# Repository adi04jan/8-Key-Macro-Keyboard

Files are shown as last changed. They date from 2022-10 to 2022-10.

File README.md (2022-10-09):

# Macro Keyboard

This project was build to provide a convinent way to control some basic task while working. Also this was a way for me to explore CH551G a wonderfull IC with so much potential.
Although the code is still a bit messy but it does what it is supposed to do.

The project was build around in a weekend so maybe some parts are not polished and may have a lot of bugs but what can we get in a weekend right !

I had a CNC milling machine lying around so I made a simple PCB with lowest possible jumpers and lowest necessary components to make the PCB in single side and with minimum assembley.

PCB Files are located inside `Macro Mini Keypad PCB Files`
and Source code is in `8xMacro_Keypad_main/8xMain_key`

## Code

Before programming the CH551G please follow [this guide](https://github.com/DeqingSun/ch55xduino "this guide") .

Once the Arduino is configured to compile code for ch551G go to `tools > User setting > 148B USB RAM` and slect this setting.

Now you can compile and upload the code in the Board via USB just remember to keep pressed the mini button behind the USB connetor while connecting the USB cable.

### Touch Switch config

There are 2 touch switch that need to be wired externally which can change the keyboard modes. 
For initial code it only change the copy paste command as in Linux terminal normal `ctrl + c `doesnt work but `ctrl + shift + c ` work.

in the 3D file behind the arrows a simple copper tap can be stuck and using wire can be connected to the pin 2 and 3 of the CH551G to change mode UP and Down.

### Changing the Keypress

Keypress can be changed in the attached Key_config.h file .
just replace the segment inside the function `Keyboard_press(   );` with what ever keypress you want to perform.
all the key press command are listed below

```

#define KEY_LEFT_CTRL   0x80
#define KEY_LEFT_SHIFT    0x81
#define KEY_LEFT_ALT    0x82
#define KEY_LEFT_GUI    0x83
#define KEY_RIGHT_CTRL    0x84
#define KEY_RIGHT_SHIFT   0x85
#define KEY_RIGHT_ALT   0x86
#define KEY_RIGHT_GUI   0x87

#define KEY_UP_ARROW    0xDA
#define KEY_DOWN_ARROW    0xD9
#define KEY_LEFT_ARROW    0xD8
#define KEY_RIGHT_ARROW   0xD7
#define KEY_BACKSPACE   0xB2
#define KEY_TAB       0xB3
#define KEY_RETURN      0xB0
#define KEY_ESC       0xB1
#define KEY_INSERT      0xD1
#define KEY_DELETE      0xD4
#define KEY_PAGE_UP     0xD3
#define KEY_PAGE_DOWN   0xD6
#define KEY_HOME      0xD2
#define KEY_END       0xD5
#define KEY_CAPS_LOCK   0xC1
#define KEY_F1        0xC2
#define KEY_F2        0xC3
#define KEY_F3        0xC4
#define KEY_F4        0xC5
#define KEY_F5        0xC6
#define KEY_F6        0xC7
#define KEY_F7        0xC8
#define KEY_F8        0xC9
#define KEY_F9        0xCA
#define KEY_F10       0xCB
#define KEY_F11       0xCC
#define KEY_F12       0xCD
#define KEY_F13       0xF0
#define KEY_F14       0xF1
#define KEY_F15       0xF2
#define KEY_F16       0xF3
#define KEY_F17       0xF4
#define KEY_F18       0xF5
#define KEY_F19       0xF6
#define KEY_F20       0xF7
#define KEY_F21       0xF8
#define KEY_F22       0xF9
#define KEY_F23       0xFA
#define KEY_F24       0xFB

 CONSUMER_POWER    = 0x30,
    CONSUMER_SLEEP = 0x32,
    
    MEDIA_RECORD = 0xB2,
    MEDIA_FAST_FORWARD    = 0xB3,
    MEDIA_REWIND    = 0xB4,
    MEDIA_NEXT    = 0xB5,
    MEDIA_PREVIOUS    = 0xB6,
    MEDIA_PREV    = 0xB6, // Alias
    MEDIA_STOP    = 0xB7,
    MEDIA_PLAY_PAUSE    = 0xCD,
    MEDIA_PAUSE    = 0xB0,
    
    MEDIA_VOLUME_MUTE    = 0xE2,
    MEDIA_VOL_MUTE = 0xE2, // Alias
    MEDIA_VOLUME_UP    = 0xE9,
    MEDIA_VOL_UP    = 0xE9, // Alias
    MEDIA_VOLUME_DOWN    = 0xEA,
    MEDIA_VOL_DOWN    = 0xEA, // Alias
    
    CONSUMER_BRIGHTNESS_UP = 0x006F,
    CONSUMER_BRIGHTNESS_DOWN = 0x0070,
    
    CONSUMER_SCREENSAVER = 0x19e,
    
    CONSUMER_PROGRAMMABLE_BUTTON_CONFIGURATION = 0x182,
    CONSUMER_CONTROL_CONFIGURATION = 0x183,
    CONSUMER_EMAIL_READER    = 0x18A,
    CONSUMER_CALCULATOR    = 0x192,
    CONSUMER_EXPLORER    = 0x194,
    
    CONSUMER_BROWSER_HOME    = 0x223,
    CONSUMER_BROWSER_BACK    = 0x224,
    CONSUMER_BROWSER_FORWARD    = 0x225,
    CONSUMER_BROWSER_REFRESH    = 0x227,
    CONSUMER_BROWSER_BOOKMARKS    = 0x22A,

    // Consumer_Page_(0x0C)    0x15
    HID_CONSUMER_UNASSIGNED        = 0x00,
    HID_CONSUMER_NUMERIC_KEY_PAD    = 0x02,    // HID type NARY
    HID_CONSUMER_PROGRAMMABLE_BUTTONS    = 0x03,    // HID type NARY
    HID_CONSUMER_MICROPHONE_CA    = 0x04,
    HID_CONSUMER_HEADPHONE_CA    = 0x05,
    HID_CONSUMER_GRAPHIC_EQUALIZER_CA    = 0x06,
    // Reserved    = 0x07-1F
    HID_CONSUMER_PLUS_10    = 0x20,    // HID type OSC
    HID_CONSUMER_PLUS_100    = 0x21,    // HID type OSC
    HID_CONSUMER_AM_SLASH_PM    = 0x22,    // HID type OSC
    // Reserved    = 0x23-3F
    HID_CONSUMER_POWER    = 0x30,    // HID type OOC
    HID_CONSUMER_RESET    = 0x31,    // HID type OSC
    HID_CONSUMER_SLEEP    = 0x32,    // HID type OSC
    HID_CONSUMER_SLEEP_AFTER    = 0x33,    // HID type OSC
    HID_CONSUMER_SLEEP_MODE    = 0x34,    // HID type RTC
    HID_CONSUMER_ILLUMINATION    = 0x35,    // HID type OOC
    HID_CONSUMER_FUNCTION_BUTTONS    = 0x36,    // HID type NARY
    // Reserved    = 0x37-3F
    HID_CONSUMER_MENU    = 0x40,    // HID type OOC
    HID_CONSUMER_MENU_PICK    = 0x41,    // HID type OSC
    HID_CONSUMER_MENU_UP    = 0x42,    // HID type OSC
    HID_CONSUMER_MENU_DOWN    = 0x43,    // HID type OSC
    HID_CONSUMER_MENU_LEFT    = 0x44,    // HID type OSC
    HID_CONSUMER_MENU_RIGHT    = 0x45,    // HID type OSC
    HID_CONSUMER_MENU_ESCAPE    = 0x46,    // HID type OSC
    HID_CONSUMER_MENU_VALUE_INCREASE    = 0x47,    // HID type OSC
    HID_CONSUMER_MENU_VALUE_DECREASE    = 0x48,    // HID type OSC
    // Reserved 0x49-5F
    HID_CONSUMER_DATA_ON_SCREEN    = 0x60,    // HID type OOC
    HID_CONSUMER_CLOSED_CAPTION    = 0x61,    // HID type OOC
    HID_CONSUMER_CLOSED_CAPTION_SELECT    = 0x62,    // HID type OSC
    HID_CONSUMER_VCR_SLASH_TV    = 0x63,    // HID type OOC
    HID_CONSUMER_BROADCAST_MODE    = 0x64,    // HID type OSC
    HID_CONSUMER_SNAPSHOT    = 0x65,    // HID type OSC
    HID_CONSUMER_STILL    = 0x66,    // HID type OSC
    // Reserved 0x67-7F
    HID_CONSUMER_SELECTION    = 0x80,    // HID type NARY
    HID_CONSUMER_ASSIGN_SELECTION    = 0x81,    // HID type OSC
    HID_CONSUMER_MODE_STEP    = 0x82,    // HID type OSC
    HID_CONSUMER_RECALL_LAST    = 0x83,    // HID type OSC
    HID_CONSUMER_ENTER_CHANNEL    = 0x84,    // HID type OSC
    HID_CONSUMER_ORDER_MOVIE    = 0x85,    // HID type OSC
    HID_CONSUMER_CHANNEL    = 0x86,    // HID type LC
    HID_CONSUMER_MEDIA_SELECTION    = 0x87,    // HID type NARY
    HID_CONSUMER_MEDIA_SELECT_COMPUTER    = 0x88,    // HID type SEL
    HID_CONSUMER_MEDIA_SELECT_TV    = 0x89,    // HID type SEL
    HID_CONSUMER_MEDIA_SELECT_WWW    = 0x8A,    // HID type SEL
    HID_CONSUMER_MEDIA_SELECT_DVD    = 0x8B,    // HID type SEL
    HID_CONSUMER_MEDIA_SELECT_TELEPHONE    = 0x8C,    // HID type SEL
    HID_CONSUMER_MEDIA_SELECT_PROGRAM_GUIDE    = 0x8D,    // HID type SEL
    HID_CONSUMER_MEDIA_SELECT_VIDEO_PHONE    = 0x8E,    // HID type SEL
    HID_CONSUMER_MEDIA_SELECT_GAMES    = 0x8F,    // HID type SEL
    HID_CONSUMER_MEDIA_SELECT_MESSAGES    = 0x90,    // HID type SEL
    HID_CONSUMER_MEDIA_SELECT_CD    = 0x91,    // HID type SEL
    HID_CONSUMER_MEDIA_SELECT_VCR    = 0x92,    // HID type SEL
    HID_CONSUMER_MEDIA_SELECT_TUNER    = 0x93,    // HID type SEL
    HID_CONSUMER_QUIT    = 0x94,    // HID type OSC
    HID_CONSUMER_HELP    = 0x95,    // HID type OOC
    HID_CONSUMER_MEDIA_SELECT_TAPE    = 0x96,    // HID type SEL
    HID_CONSUMER_MEDIA_SELECT_CABLE    = 0x97,    // HID type SEL
    HID_CONSUMER_MEDIA_SELECT_SATELLITE    = 0x98,    // HID type SEL
    HID_CONSUMER_MEDIA_SELECT_SECURITY    = 0x99,    // HID type SEL
    HID_CONSUMER_MEDIA_SELECT_HOME    = 0x9A,    // HID type SEL
    HID_CONSUMER_MEDIA_SELECT_CALL    = 0x9B,    // HID type SEL
    HID_CONSUMER_CHANNEL_INCREMENT    = 0x9C,    // HID type OSC
    HID_CONSUMER_CHANNEL_DECREMENT    = 0x9D,    // HID type OSC
    HID_CONSUMER_MEDIA_SELECT_SAP    = 0x9E,    // HID type SEL
    // Reserved 0x9F
    HID_CONSUMER_VCR_PLUS    = 0xA0,    // HID type OSC
    HID_CONSUMER_ONCE    = 0xA1,    // HID type OSC
    HID_CONSUMER_DAILY    = 0xA2,    // HID type OSC
    HID_CONSUMER_WEEKLY    = 0xA3,    // HID type OSC
    HID_CONSUMER_MONTHLY    = 0xA4,    // HID type OSC
    // Reserved 0xA5-AF
    HID_CONSUMER_PLAY    = 0xB0,    // HID type OOC
    HID_CONSUMER_PAUSE    = 0xB1,    // HID type OOC
    HID_CONSUMER_RECORD    = 0xB2,    // HID type OOC
    HID_CONSUMER_FAST_FORWARD    = 0xB3,    // HID type OOC
    HID_CONSUMER_REWIND    = 0xB4,    // HID type OOC
    HID_CONSUMER_SCAN_NEXT_TRACK    = 0xB5,    // HID type OSC
    HID_CONSUMER_SCAN_PREVIOUS_TRACK    = 0xB6,    // HID type OSC
    HID_CONSUMER_STOP    = 0xB7,    // HID type OSC
    HID_CONSUMER_EJECT    = 0xB8,    // HID type OSC
    HID_CONSUMER_RANDOM_PLAY    = 0xB9,    // HID type OOC
    HID_CONSUMER_SELECT_DISC    = 0xBA,    // HID type NARY
    HID_CONSUMER_ENTER_DISC_MC    = 0xBB,
    HID_CONSUMER_REPEAT    = 0xBC,    // HID type OSC
    HID_CONSUMER_TRACKING    = 0xBD,    // HID type LC
    HID_CONSUMER_TRACK_NORMAL    = 0xBE,    // HID type OSC
    HID_CONSUMER_SLOW_TRACKING    = 0xBF,    // HID type LC
    HID_CONSUMER_FRAME_FORWARD    = 0xC0,    // HID type RTC
    HID_CONSUMER_FRAME_BACK    = 0xC1,    // HID type RTC
    HID_CONSUMER_MARK    = 0xC2,    // HID type OSC
    HID_CONSUMER_CLEAR_MARK    = 0xC3,    // HID type OSC
    HID_CONSUMER_REPEAT_FROM_MARK    = 0xC4,    // HID type OOC
    HID_CONSUMER_RETURN_TO_MARK    = 0xC5,    // HID type OSC
    HID_CONSUMER_SEARCH_MARK_FORWARD    = 0xC6,    // HID type OSC
    HID_CONSUMER_SEARCH_MARK_BACKWARDS    = 0xC7,    // HID type OSC
    HID_CONSUMER_COUNTER_RESET    = 0xC8,    // HID type OSC
    HID_CONSUMER_SHOW_COUNTER    = 0xC9,    // HID type OSC
    HID_CONSUMER_TRACKING_INCREMENT    = 0xCA,    // HID type RTC
    HID_CONSUMER_TRACKING_DECREMENT    = 0xCB,    // HID type RTC
    HID_CONSUMER_STOP_SLASH_EJECT    = 0xCC,    // HID type OSC
    HID_CONSUMER_PLAY_SLASH_PAUSE    = 0xCD,    // HID type OSC
    HID_CONSUMER_PLAY_SLASH_SKIP    = 0xCE,    // HID type OSC
    // Reserved 0xCF-DF
    HID_CONSUMER_VOLUME    = 0xE0,    // HID type LC
    HID_CONSUMER_BALANCE    = 0xE1,    // HID type LC
    HID_CONSUMER_MUTE    = 0xE2,    // HID type OOC
    HID_CONSUMER_BASS    = 0xE3,    // HID type LC
    HID_CONSUMER_TREBLE    = 0xE4,    // HID type LC
    HID_CONSUMER_BASS_BOOST    = 0xE5,    // HID type OOC
    HID_CONSUMER_SURROUND_MODE    = 0xE6,    // HID type OSC
    HID_CONSUMER_LOUDNESS    = 0xE7,    // HID type OOC
    HID_CONSUMER_MPX    = 0xE8,    // HID type OOC
    HID_CONSUMER_VOLUME_INCREMENT    = 0xE9,    // HID type RTC
    HID_CONSUMER_VOLUME_DECREMENT    = 0xEA,    // HID type RTC
    // Reserved 0xEB-EF
    HID_CONSUMER_SPEED_SELECT    = 0xF0,    // HID type OSC
    HID_CONSUMER_PLAYBACK_SPEED    = 0xF1,    // HID type NARY
    HID_CONSUMER_STANDARD_PLAY    = 0xF2,    // HID type SEL
    HID_CONSUMER_LONG_PLAY    = 0xF3,    // HID type SEL
    HID_CONSUMER_EXTENDED_PLAY    = 0xF4,    // HID type SEL
    HID_CONSUMER_SLOW    = 0xF5,    // HID type OSC
    // Reserved 0xF6-FF
    HID_CONSUMER_FAN_ENABLE    = 0x100,    // HID type OOC
    HID_CONSUMER_FAN_SPEED    = 0x101,    // HID type LC
    HID_CONSUMER_LIGHT_ENABLE    = 0x102,    // HID type OOC
    HID_CONSUMER_LIGHT_ILLUMINATION_LEVEL    = 0x103,    // HID type LC
    HID_CONSUMER_CLIMATE_CONTROL_ENABLE    = 0x104,    // HID type OOC
    HID_CONSUMER_ROOM_TEMPERATURE    = 0x105,    // HID type LC
    HID_CONSUMER_SECURITY_ENABLE    = 0x106,    // HID type OOC
    HID_CONSUMER_FIRE_ALARM    = 0x107,    // HID type OSC
    HID_CONSUMER_POLICE_ALARM    = 0x108,    // HID type OSC
    HID_CONSUMER_PROXIMITY    = 0x109,    // HID type LC
    HID_CONSUMER_MOTION    = 0x10A,    // HID type OSC
    HID_CONSUMER_DURESS_ALARM    = 0x10B,    // HID type OSC
    HID_CONSUMER_HOLDUP_ALARM    = 0x10C,    // HID type OSC
    HID_CONSUMER_MEDICAL_ALARM    = 0x10D,    // HID type OSC
    // Reserved 0x10E-14F
    HID_CONSUMER_BALANCE_RIGHT    = 0x150,    // HID type RTC
    HID_CONSUMER_BALANCE_LEFT    = 0x151,    // HID type RTC
    HID_CONSUMER_BASS_INCREMENT    = 0x152,    // HID type RTC
    HID_CONSUMER_BASS_DECREMENT    = 0x153,    // HID type RTC
    HID_CONSUMER_TREBLE_INCREMENT    = 0x154,    // HID type RTC
    HID_CONSUMER_TREBLE_DECREMENT    = 0x155,    // HID type RTC
    // Reserved 0x156-15F
    HID_CONSUMER_SPEAKER_SYSTEM    = 0x160,    // HID type CL
    HID_CONSUMER_CHANNEL_LEFT    = 0x161,    // HID type CL
    HID_CONSUMER_CHANNEL_RIGHT    = 0x162,    // HID type CL
    HID_CONSUMER_CHANNEL_CENTER    = 0x163,    // HID type CL
    HID_CONSUMER_CHANNEL_FRONT    = 0x164,    // HID type CL
    HID_CONSUMER_CHANNEL_CENTER_FRONT    = 0x165,    // HID type CL
    HID_CONSUMER_CHANNEL_SIDE    = 0x166,    // HID type CL
    HID_CONSUMER_CHANNEL_SURROUND    = 0x167,    // HID type CL
    HID_CONSUMER_CHANNEL_LOW_FREQUENCY_ENHANCEMENT    = 0x168,    // HID type CL
    HID_CONSUMER_CHANNEL_TOP    = 0x169,    // HID type CL
    HID_CONSUMER_CHANNEL_UNKNOWN    = 0x16A,    // HID type CL
    // Reserved 0x16B-16F
    HID_CONSUMER_SUB_CHANNEL    = 0x170,    // HID type LC
    HID_CONSUMER_SUB_CHANNEL_INCREMENT    = 0x171,    // HID type OSC
    HID_CONSUMER_SUB_CHANNEL_DECREMENT    = 0x172,    // HID type OSC
    HID_CONSUMER_ALTERNATE_AUDIO_INCREMENT    = 0x173,    // HID type OSC
    HID_CONSUMER_ALTERNATE_AUDIO_DECREMENT    = 0x174,    // HID type OSC
    // Reserved 0x175-17F
    HID_CONSUMER_APPLICATION_LAUNCH_BUTTONS    = 0x180,    // HID type NARY
    HID_CONSUMER_AL_LAUNCH_BUTTON_CONFIGURATION_TOOL    = 0x181,    // HID type SEL
    HID_CONSUMER_AL_PROGRAMMABLE_BUTTON_CONFIGURATION    = 0x182,    // HID type SEL
    HID_CONSUMER_AL_CONSUMER_CONTROL_CONFIGURATION    = 0x183,    // HID type SEL
    HID_CONSUMER_AL_WORD_PROCESSOR    = 0x184,    // HID type SEL
    HID_CONSUMER_AL_TEXT_EDITOR    = 0x185,    // HID type SEL
    HID_CONSUMER_AL_SPREADSHEET    = 0x186,    // HID type SEL
    HID_CONSUMER_AL_GRAPHICS_EDITOR    = 0x187,    // HID type SEL
    HID_CONSUMER_AL_PRESENTATION_APP    = 0x188,    // HID type SEL
    HID_CONSUMER_AL_DATABASE_APP    = 0x189,    // HID type SEL
    HID_CONSUMER_AL_EMAIL_READER    = 0x18A,    // HID type SEL
    HID_CONSUMER_AL_NEWSREADER    = 0x18B,    // HID type SEL
    HID_CONSUMER_AL_VOICEMAIL    = 0x18C,    // HID type SEL
    HID_CONSUMER_AL_CONTACTS_SLASH_ADDRESS_BOOK    = 0x18D,    // HID type SEL
    HID_CONSUMER_AL_CALENDAR_SLASH_SCHEDULE    = 0x18E,    // HID type SEL
    HID_CONSUMER_AL_TASK_SLASH_PROJECT_MANAGER    = 0x18F,    // HID type SEL
    HID_CONSUMER_AL_LOG_SLASH_JOURNAL_SLASH_TIMECARD    = 0x190,    // HID type SEL
    HID_CONSUMER_AL_CHECKBOOK_SLASH_FINANCE    = 0x191,    // HID type SEL
    HID_CONSUMER_AL_CALCULATOR    = 0x192,    // HID type SEL
    HID_CONSUMER_AL_A_SLASH_V_CAPTURE_SLASH_PLAYBACK    = 0x193,    // HID type SEL
    HID_CONSUMER_AL_LOCAL_MACHINE_BROWSER    = 0x194,    // HID type SEL
    HID_CONSUMER_AL_LAN_SLASH_WAN_BROWSER    = 0x195,    // HID type SEL
    HID_CONSUMER_AL_INTERNET_BROWSER    = 0x196,    // HID type SEL
    HID_CONSUMER_AL_REMOTE_NETWORKING_SLASH_ISP_CONNECT    = 0x197,    // HID type SEL
    HID_CONSUMER_AL_NETWORK_CONFERENCE    = 0x198,    // HID type SEL
    HID_CONSUMER_AL_NETWORK_CHAT    = 0x199,    // HID type SEL
    HID_CONSUMER_AL_TELEPHONY_SLASH_DIALER    = 0x19A,    // HID type SEL
    HID_CONSUMER_AL_LOGON    = 0x19B,    // HID type SEL
    HID_CONSUMER_AL_LOGOFF    = 0x19C,    // HID type SEL
    HID_CONSUMER_AL_LOGON_SLASH_LOGOFF    = 0x19D,    // HID type SEL
    HID_CONSUMER_AL_TERMINAL_LOCK_SLASH_SCREENSAVER    = 0x19E,    // HID type SEL
    HID_CONSUMER_AL_CONTROL_PANEL    = 0x19F,    // HID type SEL
    HID_CONSUMER_AL_COMMAND_LINE_PROCESSOR_SLASH_RUN    = 0x1A0,    // HID type SEL
    HID_CONSUMER_AL_PROCESS_SLASH_TASK_MANAGER    = 0x1A1,    // HID type SEL
    HID_CONSUMER_AL_SELECT_TASK_SLASH_APPLICATION    = 0x1A2,    // HID type SEL
    HID_CONSUMER_AL_NEXT_TASK_SLASH_APPLICATION    = 0x1A3,    // HID type SEL
    HID_CONSUMER_AL_PREVIOUS_TASK_SLASH_APPLICATION    = 0x1A4,    // HID type SEL
    HID_CONSUMER_AL_PREEMPTIVE_HALT_TASK_SLASH_APPLICATION    = 0x1A5,    // HID type SEL
    HID_CONSUMER_AL_INTEGRATED_HELP_CENTER    = 0x1A6,    // HID type SEL
    HID_CONSUMER_AL_DOCUMENTS    = 0x1A7,    // HID type SEL
    HID_CONSUMER_AL_THESAURUS    = 0x1A8,    // HID type SEL
    HID_CONSUMER_AL_DICTIONARY    = 0x1A9,    // HID type SEL
    HID_CONSUMER_AL_DESKTOP    = 0x1AA,    // HID type SEL
    HID_CONSUMER_AL_SPELL_CHECK    = 0x1AB,    // HID type SEL
    HID_CONSUMER_AL_GRAMMAR_CHECK    = 0x1AC,    // HID type SEL
    HID_CONSUMER_AL_WIRELESS_STATUS    = 0x1AD,    // HID type SEL
    HID_CONSUMER_AL_KEYBOARD_LAYOUT    = 0x1AE,    // HID type SEL
    HID_CONSUMER_AL_VIRUS_PROTECTION    = 0x1AF,    // HID type SEL
    HID_CONSUMER_AL_ENCRYPTION    = 0x1B0,    // HID type SEL
    HID_CONSUMER_AL_SCREEN_SAVER    = 0x1B1,    // HID type SEL
    HID_CONSUMER_AL_ALARMS    = 0x1B2,    // HID type SEL
    HID_CONSUMER_AL_CLOCK    = 0x1B3,    // HID type SEL
    HID_CONSUMER_AL_FILE_BROWSER    = 0x1B4,    // HID type SEL
    HID_CONSUMER_AL_POWER_STATUS    = 0x1B5,    // HID type SEL
    HID_CONSUMER_AL_IMAGE_BROWSER    = 0x1B6,    // HID type SEL
    HID_CONSUMER_AL_AUDIO_BROWSER    = 0x1B7,    // HID type SEL
    HID_CONSUMER_AL_MOVIE_BROWSER    = 0x1B8,    // HID type SEL
    HID_CONSUMER_AL_DIGITAL_RIGHTS_MANAGER    = 0x1B9,    // HID type SEL
    HID_CONSUMER_AL_DIGITAL_WALLET    = 0x1BA,    // HID type SEL
    // _Reserved 0x1BB
    HID_CONSUMER_AL_INSTANT_MESSAGING    = 0x1BC,    // HID type SEL
    HID_CONSUMER_AL_OEM_FEATURES_SLASH__TIPS_SLASH_TUTORIAL_BROWSER    = 0x1BD,    // HID type SEL
    HID_CONSUMER_AL_OEM_HELP    = 0x1BE,    // HID type SEL
    HID_CONSUMER_AL_ONLINE_COMMUNITY    = 0x1BF,    // HID type SEL
    HID_CONSUMER_AL_ENTERTAINMENT_CONTENT_BROWSER    = 0x1C0,    // HID type SEL
    HID_CONSUMER_AL_ONLINE_SHOPPING_BROWSER    = 0x1C1,    // HID type SEL
    HID_CONSUMER_AL_SMARTCARD_INFORMATION_SLASH_HELP    = 0x1C2,    // HID type SEL
    HID_CONSUMER_AL_MARKET_MONITOR_SLASH_FINANCE_BROWSER    = 0x1C3,    // HID type SEL
    HID_CONSUMER_AL_CUSTOMIZED_CORPORATE_NEWS_BROWSER    = 0x1C4,    // HID type SEL
    HID_CONSUMER_AL_ONLINE_ACTIVITY_BROWSER    = 0x1C5,    // HID type SEL
    HID_CONSUMER_AL_RESEARCH_SLASH_SEARCH_BROWSER    = 0x1C6,    // HID type SEL
    HID_CONSUMER_AL_AUDIO_PLAYER    = 0x1C7,    // HID type SEL
    // Reserved 0x1C8-1FF
    HID_CONSUMER_GENERIC_GUI_APPLICATION_CONTROLS    = 0x200, // HID type NARY
    HID_CONSUMER_AC_NEW    = 0x201,    // HID type SEL
    HID_CONSUMER_AC_OPEN    = 0x202,    // HID type SEL
    HID_CONSUMER_AC_CLOSE    = 0x203,    // HID type SEL
    HID_CONSUMER_AC_EXIT    = 0x204,    // HID type SEL
    HID_CONSUMER_AC_MAXIMIZE    = 0x205,    // HID type SEL
    HID_CONSUMER_AC_MINIMIZE    = 0x206,    // HID type SEL
    HID_CONSUMER_AC_SAVE    = 0x207,    // HID type SEL
    HID_CONSUMER_AC_PRINT    = 0x208,    // HID type SEL
    HID_CONSUMER_AC_PROPERTIES    = 0x209,    // HID type SEL
    HID_CONSUMER_AC_UNDO    = 0x21A,    // HID type SEL
    HID_CONSUMER_AC_COPY    = 0x21B,    // HID type SEL
    HID_CONSUMER_AC_CUT    = 0x21C,    // HID type SEL
    HID_CONSUMER_AC_PASTE    = 0x21D,    // HID type SEL
    HID_CONSUMER_AC_SELECT_ALL    = 0x21E,    // HID type SEL
    HID_CONSUMER_AC_FIND    = 0x21F,    // HID type SEL
    HID_CONSUMER_AC_FIND_AND_REPLACE    = 0x220,    // HID type SEL
    HID_CONSUMER_AC_SEARCH    = 0x221,    // HID type SEL
    HID_CONSUMER_AC_GO_TO    = 0x222,    // HID type SEL
    HID_CONSUMER_AC_HOME    = 0x223,    // HID type SEL
    HID_CONSUMER_AC_BACK    = 0x224,    // HID type SEL
    HID_CONSUMER_AC_FORWARD    = 0x225,    // HID type SEL
    HID_CONSUMER_AC_STOP    = 0x226,    // HID type SEL
    HID_CONSUMER_AC_REFRESH    = 0x227,    // HID type SEL
    HID_CONSUMER_AC_PREVIOUS_LINK    = 0x228,    // HID type SEL
    HID_CONSUMER_AC_NEXT_LINK    = 0x229,    // HID type SEL
    HID_CONSUMER_AC_BOOKMARKS    = 0x22A,    // HID type SEL
    HID_CONSUMER_AC_HISTORY    = 0x22B,    // HID type SEL
    HID_CONSUMER_AC_SUBSCRIPTIONS    = 0x22C,    // HID type SEL
    HID_CONSUMER_AC_ZOOM_IN    = 0x22D,    // HID type SEL
    HID_CONSUMER_AC_ZOOM_OUT    = 0x22E,    // HID type SEL
    HID_CONSUMER_AC_ZOOM    = 0x22F,    // HID type LC
    HID_CONSUMER_AC_FULL_SCREEN_VIEW    = 0x230,    // HID type SEL
    HID_CONSUMER_AC_NORMAL_VIEW    = 0x231,    // HID type SEL
    HID_CONSUMER_AC_VIEW_TOGGLE    = 0x232,    // HID type SEL
    HID_CONSUMER_AC_SCROLL_UP    = 0x233,    // HID type SEL
    HID_CONSUMER_AC_SCROLL_DOWN    = 0x234,    // HID type SEL
    HID_CONSUMER_AC_SCROLL    = 0x235,    // HID type LC
    HID_CONSUMER_AC_PAN_LEFT    = 0x236,    // HID type SEL
    HID_CONSUMER_AC_PAN_RIGHT    = 0x237,    // HID type SEL
    HID_CONSUMER_AC_PAN    = 0x238,    // HID type LC
    HID_CONSUMER_AC_NEW_WINDOW    = 0x239,    // HID type SEL
    HID_CONSUMER_AC_TILE_HORIZONTALLY    = 0x23A,    // HID type SEL
    HID_CONSUMER_AC_TILE_VERTICALLY    = 0x23B,    // HID type SEL
    HID_CONSUMER_AC_FORMAT    = 0x23C,    // HID type SEL
    HID_CONSUMER_AC_EDIT    = 0x23D,    // HID type SEL
    HID_CONSUMER_AC_BOLD    = 0x23E,    // HID type SEL
    HID_CONSUMER_AC_ITALICS    = 0x23F,    // HID type SEL
    HID_CONSUMER_AC_UNDERLINE    = 0x240,    // HID type SEL
    HID_CONSUMER_AC_STRIKETHROUGH    = 0x241,    // HID type SEL
    HID_CONSUMER_AC_SUBSCRIPT    = 0x242,    // HID type SEL
    HID_CONSUMER_AC_SUPERSCRIPT    = 0x243,    // HID type SEL
    HID_CONSUMER_AC_ALL_CAPS    = 0x244,    // HID type SEL
    HID_CONSUMER_AC_ROTATE    = 0x245,    // HID type SEL
    HID_CONSUMER_AC_RESIZE    = 0x246,    // HID type SEL
    HID_CONSUMER_AC_FLIP_HORIZONTAL    = 0x247,    // HID type SEL
    HID_CONSUMER_AC_FLIP_VERTICAL    = 0x248,    // HID type SEL
    HID_CONSUMER_AC_MIRROR_HORIZONTAL    = 0x249,    // HID type SEL
    HID_CONSUMER_AC_MIRROR_VERTICAL    = 0x24A,    // HID type SEL
    HID_CONSUMER_AC_FONT_SELECT    = 0x24B,    // HID type SEL
    HID_CONSUMER_AC_FONT_COLOR    = 0x24C,    // HID type SEL
    HID_CONSUMER_AC_FONT_SIZE    = 0x24D,    // HID type SEL
    HID_CONSUMER_AC_JUSTIFY_LEFT    = 0x24E,    // HID type SEL
    HID_CONSUMER_AC_JUSTIFY_CENTER_H    = 0x24F,    // HID type SEL
    HID_CONSUMER_AC_JUSTIFY_RIGHT    = 0x250,    // HID type SEL
    HID_CONSUMER_AC_JUSTIFY_BLOCK_H    = 0x251,    // HID type SEL
    HID_CONSUMER_AC_JUSTIFY_TOP    = 0x252,    // HID type SEL
    HID_CONSUMER_AC_JUSTIFY_CENTER_V    = 0x253,    // HID type SEL
    HID_CONSUMER_AC_JUSTIFY_BOTTOM    = 0x254,    // HID type SEL
    HID_CONSUMER_AC_JUSTIFY_BLOCK_V    = 0x255,    // HID type SEL
    HID_CONSUMER_AC_INDENT_DECREASE    = 0x256,    // HID type SEL
    HID_CONSUMER_AC_INDENT_INCREASE    = 0x257,    // HID type SEL
    HID_CONSUMER_AC_NUMBERED_LIST    = 0x258,    // HID type SEL
    HID_CONSUMER_AC_RESTART_NUMBERING    = 0x259,    // HID type SEL
    HID_CONSUMER_AC_BULLETED_LIST    = 0x25A,    // HID type SEL
    HID_CONSUMER_AC_PROMOTE    = 0x25B,    // HID type SEL
    HID_CONSUMER_AC_DEMOTE    = 0x25C,    // HID type SEL
    HID_CONSUMER_AC_YES    = 0x25D,    // HID type SEL
    HID_CONSUMER_AC_NO    = 0x25E,    // HID type SEL
    HID_CONSUMER_AC_CANCEL    = 0x25F,    // HID type SEL
    HID_CONSUMER_AC_CATALOG    = 0x260,    // HID type SEL
    HID_CONSUMER_AC_BUY_SLASH_CHECKOUT    = 0x261,    // HID type SEL
    HID_CONSUMER_AC_ADD_TO_CART    = 0x262,    // HID type SEL
    HID_CONSUMER_AC_EXPAND    = 0x263,    // HID type SEL
    HID_CONSUMER_AC_EXPAND_ALL    = 0x264,    // HID type SEL
    HID_CONSUMER_AC_COLLAPSE    = 0x265,    // HID type SEL
    HID_CONSUMER_AC_COLLAPSE_ALL    = 0x266,    // HID type SEL
    HID_CONSUMER_AC_PRINT_PREVIEW    = 0x267,    // HID type SEL
    HID_CONSUMER_AC_PASTE_SPECIAL    = 0x268,    // HID type SEL
    HID_CONSUMER_AC_INSERT_MODE    = 0x269,    // HID type SEL
    HID_CONSUMER_AC_DELETE    = 0x26A,    // HID type SEL
    HID_CONSUMER_AC_LOCK    = 0x26B,    // HID type SEL
    HID_CONSUMER_AC_UNLOCK    = 0x26C,    // HID type SEL
    HID_CONSUMER_AC_PROTECT    = 0x26D,    // HID type SEL
    HID_CONSUMER_AC_UNPROTECT    = 0x26E,    // HID type SEL
    HID_CONSUMER_AC_ATTACH_COMMENT    = 0x26F,    // HID type SEL
    HID_CONSUMER_AC_DELETE_COMMENT    = 0x270,    // HID type SEL
    HID_CONSUMER_AC_VIEW_COMMENT    = 0x271,    // HID type SEL
    HID_CONSUMER_AC_SELECT_WORD    = 0x272,    // HID type SEL
    HID_CONSUMER_AC_SELECT_SENTENCE    = 0x273,    // HID type SEL
    HID_CONSUMER_AC_SELECT_PARAGRAPH    = 0x274,    // HID type SEL
    HID_CONSUMER_AC_SELECT_COLUMN    = 0x275,    // HID type SEL
    HID_CONSUMER_AC_SELECT_ROW    = 0x276,    // HID type SEL
    HID_CONSUMER_AC_SELECT_TABLE    = 0x277,    // HID type SEL
    HID_CONSUMER_AC_SELECT_OBJECT    = 0x278,    // HID type SEL
    HID_CONSUMER_AC_REDO_SLASH_REPEAT    = 0x279,    // HID type SEL
    HID_CONSUMER_AC_SORT    = 0x27A,    // HID type SEL
    HID_CONSUMER_AC_SORT_ASCENDING    = 0x27B,    // HID type SEL
    HID_CONSUMER_AC_SORT_DESCENDING    = 0x27C,    // HID type SEL
    HID_CONSUMER_AC_FILTER    = 0x27D,    // HID type SEL
    HID_CONSUMER_AC_SET_CLOCK    = 0x27E,    // HID type SEL
    HID_CONSUMER_AC_VIEW_CLOCK    = 0x27F,    // HID type SEL
    HID_CONSUMER_AC_SELECT_TIME_ZONE    = 0x280,    // HID type SEL
    HID_CONSUMER_AC_EDIT_TIME_ZONES    = 0x281,    // HID type SEL
    HID_CONSUMER_AC_SET_ALARM    = 0x282,    // HID type SEL
    HID_CONSUMER_AC_CLEAR_ALARM    = 0x283,    // HID type SEL
    HID_CONSUMER_AC_SNOOZE_ALARM    = 0x284,    // HID type SEL
    HID_CONSUMER_AC_RESET_ALARM    = 0x285,    // HID type SEL
    HID_CONSUMER_AC_SYNCHRONIZE    = 0x286,    // HID type SEL
    HID_CONSUMER_AC_SEND_SLASH_RECEIVE    = 0x287,    // HID type SEL
    HID_CONSUMER_AC_SEND_TO    = 0x288,    // HID type SEL
    HID_CONSUMER_AC_REPLY    = 0x289,    // HID type SEL
    HID_CONSUMER_AC_REPLY_ALL    = 0x28A,    // HID type SEL
    HID_CONSUMER_AC_FORWARD_MSG    = 0x28B,    // HID type SEL
    HID_CONSUMER_AC_SEND    = 0x28C,    // HID type SEL
    HID_CONSUMER_AC_ATTACH_FILE    = 0x28D,    // HID type SEL
    HID_CONSUMER_AC_UPLOAD    = 0x28E,    // HID type SEL
    HID_CONSUMER_AC_DOWNLOAD_SAVE_TARGET_AS    = 0x28F,    // HID type SEL
    HID_CONSUMER_AC_SET_BORDERS    = 0x290,    // HID type SEL
    HID_CONSUMER_AC_INSERT_ROW    = 0x291,    // HID type SEL
    HID_CONSUMER_AC_INSERT_COLUMN    = 0x292,    // HID type SEL
    HID_CONSUMER_AC_INSERT_FILE    = 0x293,    // HID type SEL
    HID_CONSUMER_AC_INSERT_PICTURE    = 0x294,    // HID type SEL
    HID_CONSUMER_AC_INSERT_OBJECT    = 0x295,    // HID type SEL
    HID_CONSUMER_AC_INSERT_SYMBOL    = 0x296,    // HID type SEL
    HID_CONSUMER_AC_SAVE_AND_CLOSE    = 0x297,    // HID type SEL
    HID_CONSUMER_AC_RENAME    = 0x298,    // HID type SEL
    HID_CONSUMER_AC_MERGE    = 0x299,    // HID type SEL
    HID_CONSUMER_AC_SPLIT    = 0x29A,    // HID type SEL
    HID_CONSUMER_AC_DISRIBUTE_HORIZONTALLY    = 0x29B,    // HID type SEL
    HID_CONSUMER_AC_DISTRIBUTE_VERTICALLY    = 0x29C,    // HID type SEL

```

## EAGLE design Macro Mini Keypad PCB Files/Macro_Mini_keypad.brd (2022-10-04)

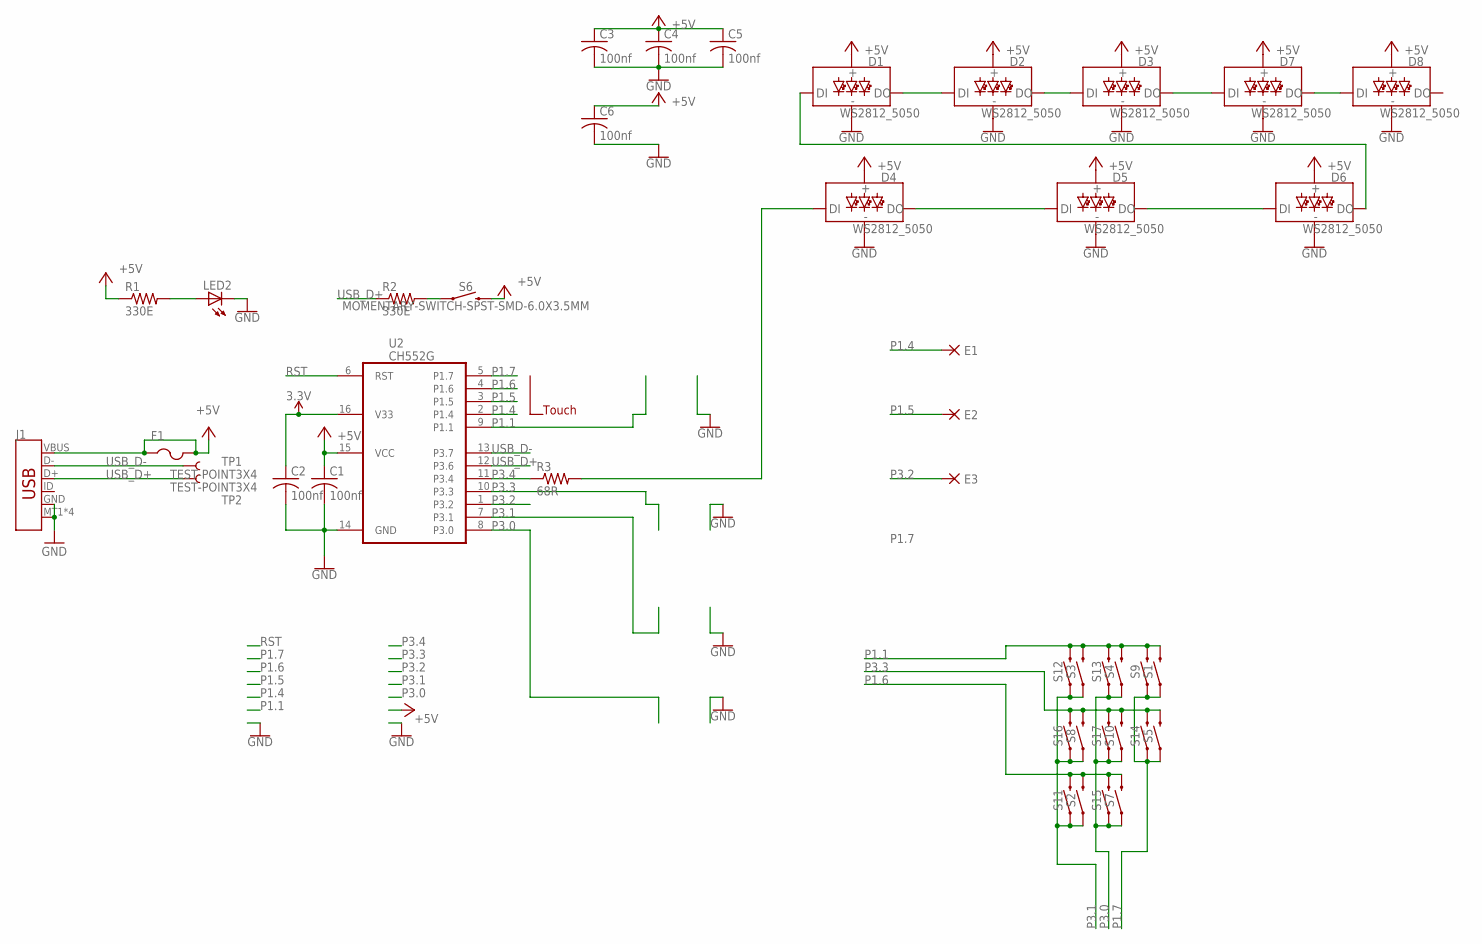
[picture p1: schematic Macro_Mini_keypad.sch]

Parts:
C1, C2, C3, C4, C5, C6: 100nf; C1206
D1, D2, D3, D4, D5, D6, D7, D8: WS2812_5050; WS2812-5X5-4PIN
E1, E2, E3: DPADS_PAD-0400-S; DPADS_0400-S
F1: PTCFUSE-1206; R1206; LCSC C151162
J1: USB_MICRO-B_SMT; USB-MICROB
LED2: LEDCHIPLED_1206; CHIPLED_1206
R1, R2: 330E; R1206
R3: 68R; R1206
S1, S2, S3, S4, S5, S7, S8, S10: MECHANICAL-KEYBOARD_CUSTOM1U; CHERRY-MX-LED-1U
S6: MOMENTARY-SWITCH-SPST-SMD-6.0X3.5MM; TACTILE_SWITCH_SMD_6.0X3.5MM
S9, S11, S12, S13, S14, S15, S16, S17: MOMENTARY-SWITCH-SPST-PTH-12MM; TACTILE_SWITCH_PTH_12MM
TP1, TP2: TEST-POINT3X4; PAD.03X.04
U2: CH552G; MY_IC_SO16; LCSC C111292

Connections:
3.3V: C2.1, U2.16 (V33)
+5V: C1.1, C3.1, C4.1, C5.1, C6.1, D1.VCC, D2.VCC, D3.VCC, D4.VCC, D5.VCC, D6.VCC, D7.VCC, D8.VCC, F1.1, F1.2, J1.VBUS, R1.1, S6.2, U2.15 (VCC)
GND: C1.2, C2.2, C3.2, C4.2, C5.2, C6.2, D1.GND, D2.GND, D3.GND, D4.GND, D5.GND, D6.GND, D7.GND, D8.GND, J1.GND, J1.MT1 (SHIELD), J1.MT2 (SHIELD), J1.P$1 (SHIELD), J1.P$2 (SHIELD), LED2.C, U2.14 (GND)
unnamed: R2.2, S6.1
unnamed: D4.DI, R3.2
unnamed: LED2.A, R1.2
unnamed: D4.DO, D5.DI
unnamed: D5.DO, D6.DI
unnamed: D1.DI, D6.DO
unnamed: D1.DO, D2.DI
unnamed: D2.DO, D3.DI
unnamed: D3.DO, D7.DI
unnamed: D7.DO, D8.DI
P1.1: S1.S2 (2), S3.S2 (2), S4.S2 (2), S9.3 (2), S12.3 (2), S13.3 (2), U2.9 (P1.1)
P1.4: E1.PAD, U2.2 (P1.4)
P1.5: E2.PAD, U2.3 (P1.5)
P1.6: S2.S2 (2), S7.S2 (2), S11.3 (2), S15.3 (2), U2.4 (P1.6)
P1.7: S1.S1 (1), S5.S1 (1), S9.1, S14.1, U2.5 (P1.7)
P3.0: S4.S1 (1), S7.S1 (1), S10.S1 (1), S13.1, S15.1, S17.1, U2.8 (P3.0)
P3.1: S2.S1 (1), S3.S1 (1), S8.S1 (1), S11.1, S12.1, S16.1, U2.7 (P3.1)
P3.2: E3.PAD, U2.1 (P3.2)
P3.3: S5.S2 (2), S8.S2 (2), S10.S2 (2), S14.3 (2), S16.3 (2), S17.3 (2), U2.10 (P3.3)
P3.4: R3.1, U2.11 (P3.4)
RST: U2.6 (RST)
USB_D+: J1.D+, R2.1, TP2.P$1, U2.12 (P3.6)
USB_D-: J1.D-, TP1.P$1, U2.13 (P3.7)

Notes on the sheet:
Touch

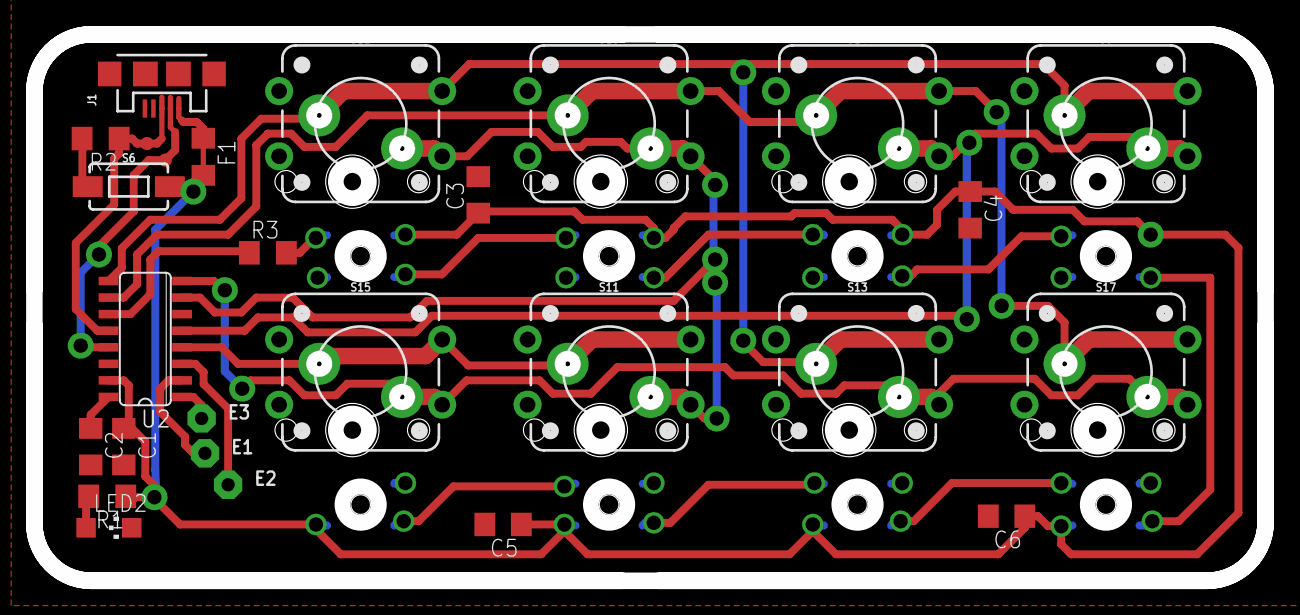
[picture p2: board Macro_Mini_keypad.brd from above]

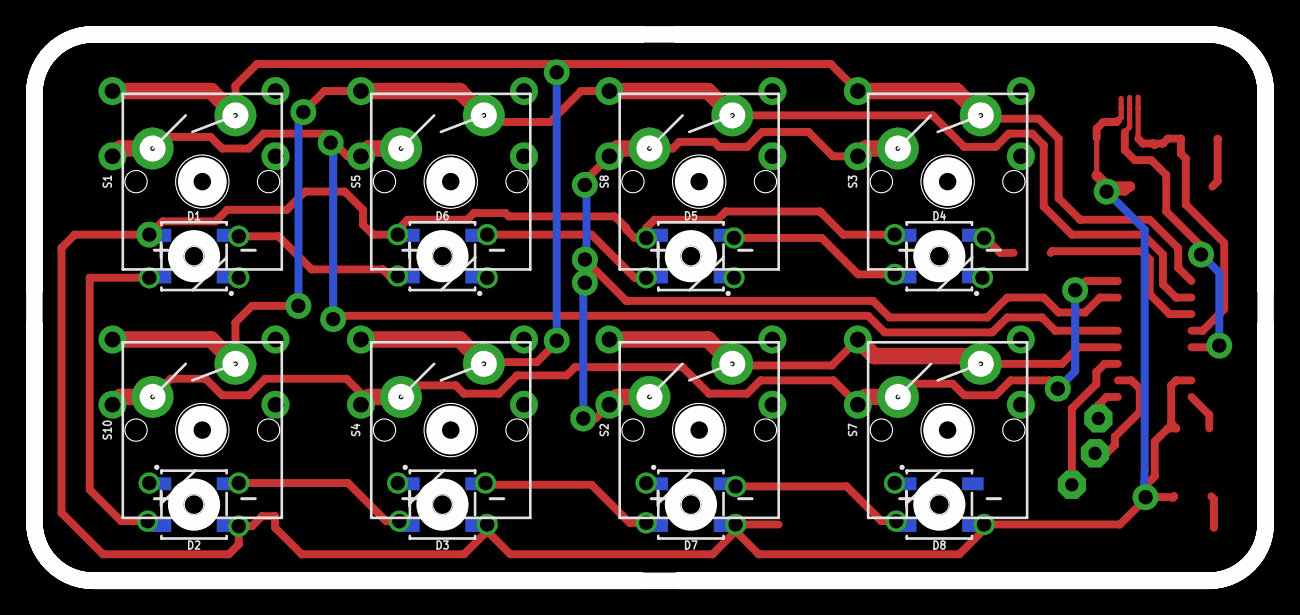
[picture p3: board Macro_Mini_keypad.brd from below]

Board: 2 copper layers, 94.4 x 41.9 mm, 43 parts (16 on the bottom side), 25 nets.

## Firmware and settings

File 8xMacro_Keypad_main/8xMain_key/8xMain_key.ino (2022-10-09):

/*
  HID Keyboard example


  created 2020
  by Deqing Sun for use with CH55xduino

  This example code is in the public domain.

*/

//For windows user, if you ever played with other HID device with the same PID C55D
//You may need to uninstall the previous driver completely


#ifndef USER_USB_RAM
#error "This example needs to be compiled with a USER USB setting"
#endif

#include "src/userUsbHidMediaKeyboard/USBHIDMediaKeyboard.h"

#include <TouchKey.h>
#include <WS2812.h>
#define NUM_LEDS 8
#define COLOR_PER_LEDS 3
#define NUM_BYTES (NUM_LEDS*COLOR_PER_LEDS)

#if NUM_BYTES > 255
#error "NUM_BYTES can not be larger than 255."
#endif
#include "Key_config.h"

__xdata uint8_t ledData[NUM_BYTES];



__xdata uint8_t r, g, b;


bool B_1 = false;
bool B_2 = false;
bool B_3 = false;
bool B_4 = false;
bool T_1 = false;
bool T_2 = false;


uint8_t Keyboardlevel = 0;
#define BUTIN_1 11
#define BUTIN_2 33
#define BUTIN_3 16



#define BUTOUT_1 31
#define BUTOUT_2 30
#define BUTOUT_3 17

uint8_t prevSensorValue = 0;
bool button1PressPrev1 = false;
bool button1PressPrev2 = false;
bool button1PressPrev3 = false;
bool button1PressPrev4 = false;


bool button1PressPrev = false;


void setup() {
  USBInit();
  pinMode(BUTIN_1, INPUT_PULLUP);
  pinMode(BUTIN_2, INPUT_PULLUP);
  pinMode(BUTIN_3, INPUT_PULLUP);
  pinMode(BUTOUT_1, OUTPUT);
  pinMode(BUTOUT_2, OUTPUT);
  pinMode(BUTOUT_3, OUTPUT);

  digitalWrite(BUTOUT_1, HIGH);
  digitalWrite(BUTOUT_2, HIGH);
  digitalWrite(BUTOUT_3, HIGH);
  TouchKey_begin(  (1 << 2) | (1 << 3) ); //Enable all 6 channels: TIN0(P1.0), TIN1(P1.1), TIN2(P1.4), TIN3(P1.5), TIN4(P1.6), TIN5(P1.7)

  // In most cases you don't need to adjust parameters. But if you do, test with TouchKeyTuneParameter example

  //refer to AN3891 MPR121 Baseline System for more details
  TouchKey_SetMaxHalfDelta(25);      //increase if sensor value are more noisy
  TouchKey_SetNoiseHalfDelta(15);    //If baseline need to adjust at higher rate, increase this value
  TouchKey_SetNoiseCountLimit(15);  //If baseline need to adjust faster, increase this value
  TouchKey_SetFilterDelayLimit(4);  //make overall adjustment slopwer

  TouchKey_SetTouchThreshold(200);  //Bigger touch pad can use a bigger value
  TouchKey_SetReleaseThreshold(180); //Smaller than touch threshold

}



void touch_routine() {

  TouchKey_Process();
  uint8_t touchResult = TouchKey_Get();

  if (touchResult & (1 << 2)) {
    T_1 = true;
    Keyboardlevel++;
    if (Keyboardlevel > 1)Keyboardlevel = 0;
    for (int c = 0; c < 7; c++) {
      set_pixel_for_GRB_LED(ledData, c, 255, 0, 0);
    }
    neopixel_show_P3_4(ledData, NUM_BYTES); //Possible to use other pins.
    delay(350);  // Pause for a moment
    delay(1);
  }
  else {

    T_1 = false;
    delay(1);

  }

  if (touchResult & (1 << 3)) {

    T_2 = true;

    for (int c = 0; c < 7; c++) {
      set_pixel_for_GRB_LED(ledData, c, 0, 255, 0);
    }
    neopixel_show_P3_4(ledData, NUM_BYTES); //Possible to use other pins.
    delay(350);  // Pause for a moment
    Keyboardlevel--;
    if (Keyboardlevel < 0)Keyboardlevel = 0;
    delay(1);
  }
  else {
    T_2 = false;
    delay(1);

  }

}

void Button_Routine() {

  digitalWrite(BUTOUT_1, LOW);
  digitalWrite(BUTOUT_2, HIGH);
  digitalWrite(BUTOUT_3, HIGH);
  delay(1);

  if (digitalRead(BUTIN_1) != HIGH) {
    delay(25);
    if (digitalRead(BUTIN_1) != HIGH) {
      if (Keyboardlevel == 0) {
        Keypad(3);
      }
      else if (Keyboardlevel == 1) {

        Keypad1(3);
      }
      else {
        Keyboardlevel = 0;
      }
    }
  }

  else if (digitalRead(BUTIN_2) != HIGH) {
    delay(25);
    if (digitalRead(BUTIN_2) != HIGH) {
      if (Keyboardlevel == 0) {
        Keypad(2);
      }
      else if (Keyboardlevel == 1) {

        Keypad1(2);
      }
      else {
        Keyboardlevel = 0;
      }
      //while (digitalRead(BUTIN_2) != HIGH)delay(100);
    }
  }

  else if (digitalRead(BUTIN_3) != HIGH) {
    delay(25);
    if (digitalRead(BUTIN_3) != HIGH) {
      if (Keyboardlevel == 0) {
        Keypad(6);
      }
      else if (Keyboardlevel == 1) {

        Keypad1(6);
      }
      else {
        Keyboardlevel = 0;
      }
    }
  }
  ///***************end of 1 column


  digitalWrite(BUTOUT_1, HIGH);
  digitalWrite(BUTOUT_2, LOW);
  digitalWrite(BUTOUT_3, HIGH);
  delay(1);

  if (digitalRead(BUTIN_1) != HIGH) {
    delay(25);
    if (digitalRead(BUTIN_1) != HIGH) {
      if (Keyboardlevel == 0) {
        Keypad(5);
      }
      else if (Keyboardlevel == 1) {

        Keypad1(5);
      }
      else {
        Keyboardlevel = 0;
      }
    }
  }

  else  if (digitalRead(BUTIN_2) != HIGH) {
    delay(25);
    if (digitalRead(BUTIN_2) != HIGH) {
      if (Keyboardlevel == 0) {
        Keypad(4);
      }
      else if (Keyboardlevel == 1) {

        Keypad1(4);
      }
      else {
        Keyboardlevel = 0;
      }
    }
  }

  else  if (digitalRead(BUTIN_3) != HIGH) {
    delay(25);
    if (digitalRead(BUTIN_3) != HIGH) {
      if (Keyboardlevel == 0) {
        Keypad(7);
      }
      else if (Keyboardlevel == 1) {

        Keypad1(7);
      }
      else {
        Keyboardlevel = 0;
      }
    }
  }
  ///***************end of 2 column


  digitalWrite(BUTOUT_1, HIGH);
  digitalWrite(BUTOUT_2, HIGH);
  digitalWrite(BUTOUT_3, LOW);
  delay(1);

  if (digitalRead(BUTIN_1) != HIGH) {
    delay(25);
    if (digitalRead(BUTIN_1) != HIGH) {
      if (Keyboardlevel == 0) {
        Keypad(0);
      }
      else if (Keyboardlevel == 1) {

        Keypad1(0);
      }
      else {
        Keyboardlevel = 0;
      }
    }
  }

  else  if (digitalRead(BUTIN_2) != HIGH) {
    delay(25);
    if (digitalRead(BUTIN_2) != HIGH) {
      if (Keyboardlevel == 0) {
        Keypad(1);
      }
      else if (Keyboardlevel == 1) {

        Keypad1(1);
      }
      else {
        Keyboardlevel = 0;
      }
      //  while (digitalRead(BUTIN_2) != HIGH)delay(100);
    }
  }

  else  if (digitalRead(BUTIN_3) != HIGH) {
    delay(25);
    if (digitalRead(BUTIN_3) != HIGH) {
      Keypad(8);
      //  while (digitalRead(BUTIN_3) != HIGH)delay(100);
    }
  }
  ///***************end of 3 column

}
void ColorHSV1(__xdata uint16_t hue) {

  hue = (hue * 1530L + 32768) / 65536;

  if (hue < 510) { // Red to Green-1
    b = 0;
    if (hue < 255) { //   Red to Yellow-1
      r = 255;
      g = hue;       //     g = 0 to 254
    } else {         //   Yellow to Green-1
      r = 510 - hue; //     r = 255 to 1
      g = 255;
    }
  } else if (hue < 1020) { // Green to Blue-1
    r = 0;
    if (hue < 765) { //   Green to Cyan-1
      g = 255;
      b = hue - 510;  //     b = 0 to 254
    } else {          //   Cyan to Blue-1
      g = 1020 - hue; //     g = 255 to 1
      b = 255;
    }
  } else if (hue < 1530) { // Blue to Red-1
    g = 0;
    if (hue < 1275) { //   Blue to Magenta-1
      r = hue - 1020; //     r = 0 to 254
      b = 255;
    } else { //   Magenta to Red-1
      r = 255;
      b = 1530 - hue; //     b = 255 to 1
    }
  } else { // Last 0.5 Red (quicker than % operator)
    r = 255;
    g = b = 0;
  }

}
void rainbow(int wait) {

  for (__xdata long firstPixelHue = 0; firstPixelHue < 3 * 65536; firstPixelHue += 256) {
    for (int i = 0; i < NUM_LEDS; i++) { // For each pixel in strip...

      int pixelHue = firstPixelHue + (i * 65536L / NUM_LEDS);
      ColorHSV1(pixelHue);
      // before assigning to each pixel:
      set_pixel_for_GRB_LED(ledData, i, r, g, b);

      Button_Routine();
      touch_routine();
    }
    neopixel_show_P3_4(ledData, NUM_BYTES); //Possible to use other pins.
    delay(wait);  // Pause for a moment
  }
}


void loop() {
  // put your main code here, to run repeatedly:AAA
  // touch_routine();
  // Button_Routine();
  //Keypad(0);
  rainbow(1);


}

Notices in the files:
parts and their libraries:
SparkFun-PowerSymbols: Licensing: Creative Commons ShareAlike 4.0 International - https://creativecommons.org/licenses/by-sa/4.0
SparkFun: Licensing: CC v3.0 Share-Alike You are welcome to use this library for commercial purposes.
